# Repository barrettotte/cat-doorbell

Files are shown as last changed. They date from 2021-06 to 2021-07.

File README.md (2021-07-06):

# cat-doorbell

A proximity sensor to detect my cat outside my door and flash an LED at my desk.

## Summary

I generally have noise cancelling headphones on and my cat will sit outside my door
meowing late at night when it wants to come in.

This project has two modules, a transmitter and receiver.
The transmitter module will detect my cat using a proximity sensor and send an RF
signal to the receiver module. The receiver module will activate an LED for three seconds
upon receiving an RF signal.

On the receiver module there is an optional piezo speaker that can be muted/unmuted to 
trigger at the same time as the LED. I feel like it might get annoying hence the mute button.

## Part List

- 2 x Arduino Nano ATmega328
- 2 x NRF24L01 2.4GHz Transceiver module
- 2 x 100μF electrolytic capacitor
- 2 x Micro USB breakout board
- 2 x LD1117V33 3.3V linear voltage regulator
- 2 x Red LED
- 2 x 570Ω resistor
- 1 x 100Ω resistor
- 1 x Piezo Speaker
- 1 x Switch
- 1 x Ultrasonic module HC-SR04

## Images

### Receiver

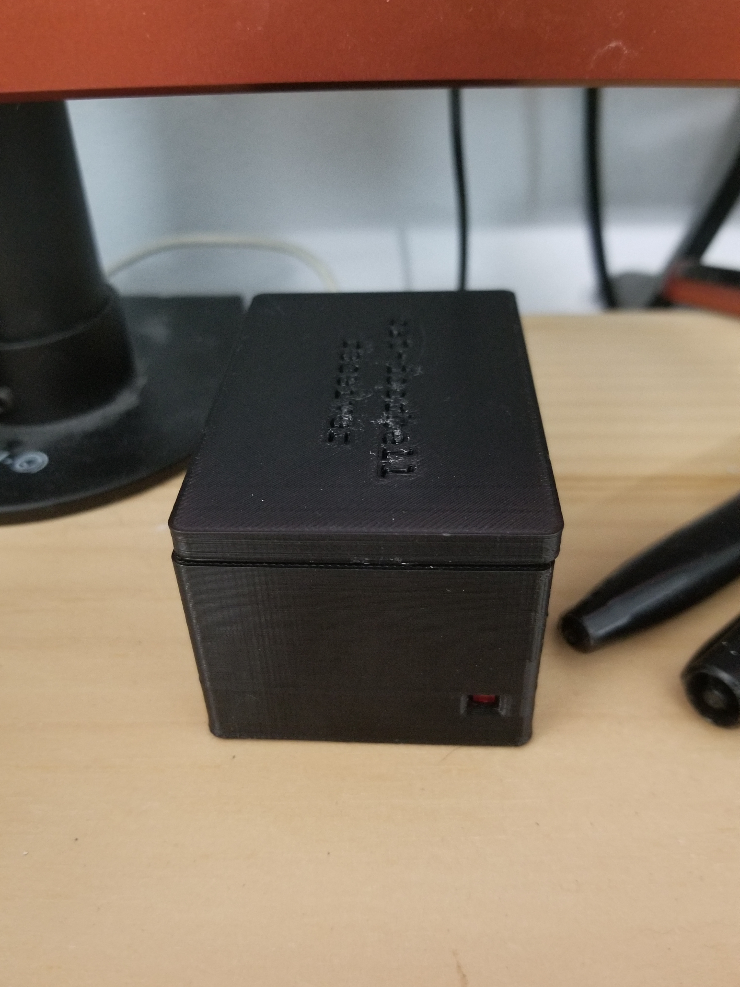
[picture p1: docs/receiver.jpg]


### Transmitter

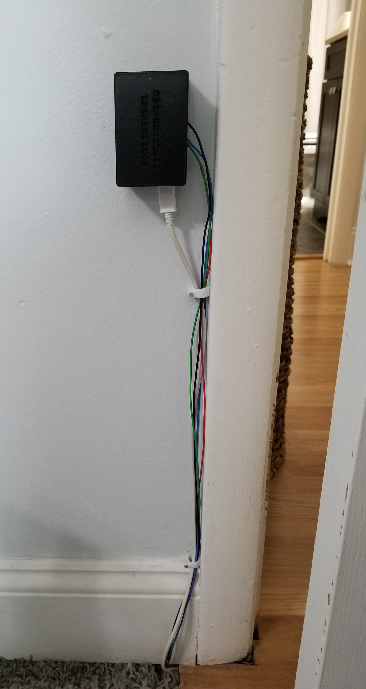
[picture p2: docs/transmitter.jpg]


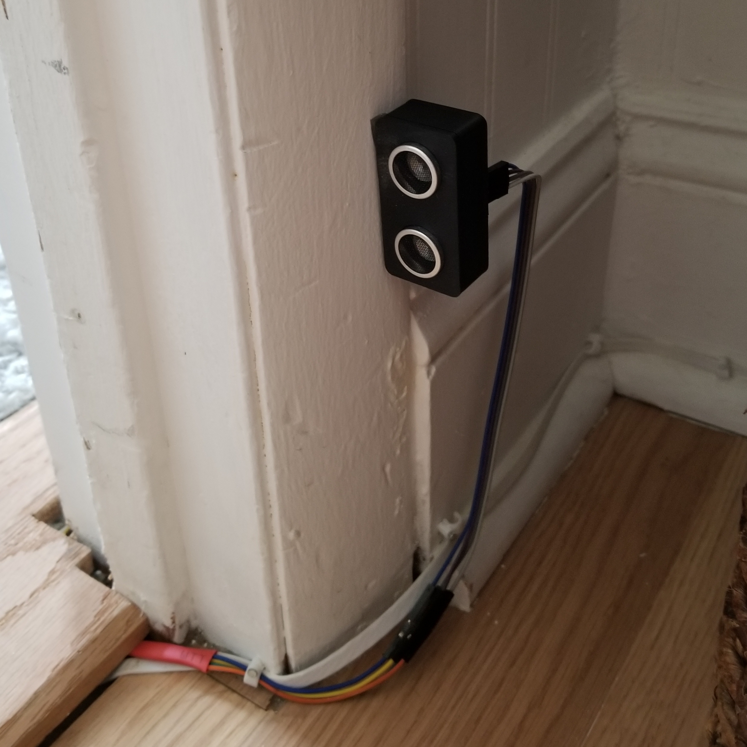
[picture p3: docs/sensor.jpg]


## Improvements

Stuff I thought about as the project was pretty much done

- Use terminal blocks instead of four dupont cables
- A potentiometer to adjust ultrasonic sensor max range (useful for tuning)

## References

- [Platformio SparkFun Arduino Nano ATmega328](https://docs.platformio.org/en/latest/boards/atmelavr/nanoatmega328.html)
- [HC-SR04 Ultrasonic Sensor - Last Minute Engineers](https://lastminuteengineers.com/arduino-sr04-ultrasonic-sensor-tutorial/)
- [NRF24L01 - Last Minute Engineers](https://lastminuteengineers.com/nrf24l01-arduino-wireless-communication/)

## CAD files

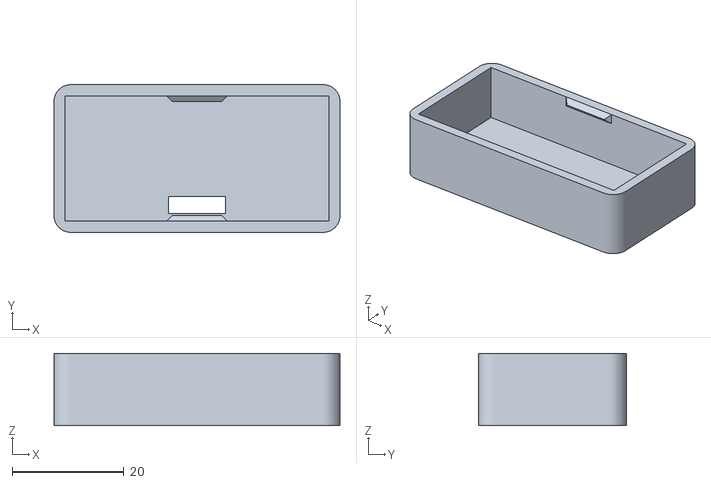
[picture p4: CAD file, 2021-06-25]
cad/HCSR04/HCSR04-bottom.stl
51.3 x 26.5 x 13.0

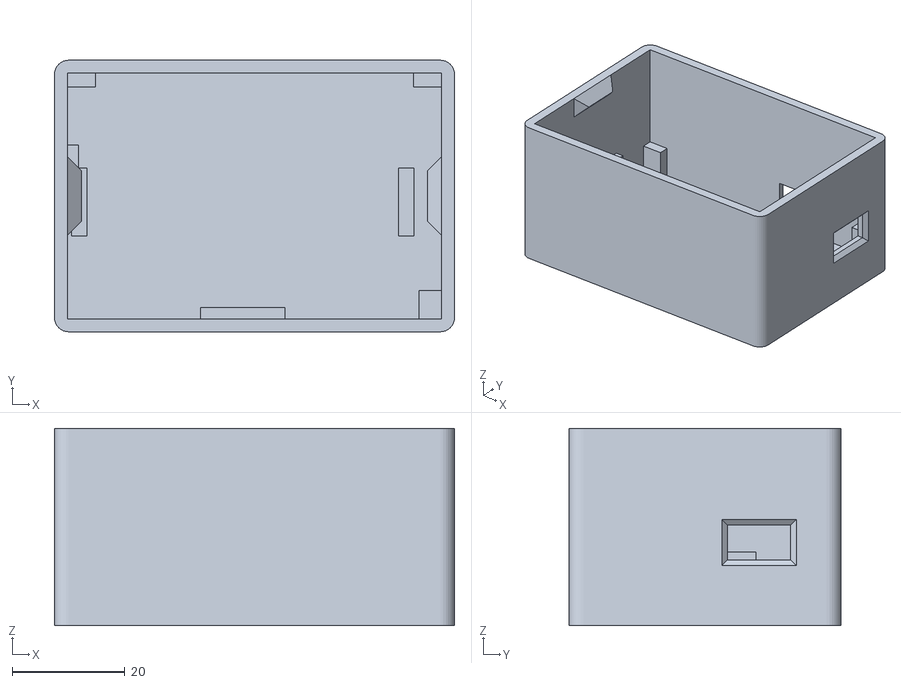
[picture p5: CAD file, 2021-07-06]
cad/receiver/receiver-bottom.stl
71.0 x 48.2 x 35.0

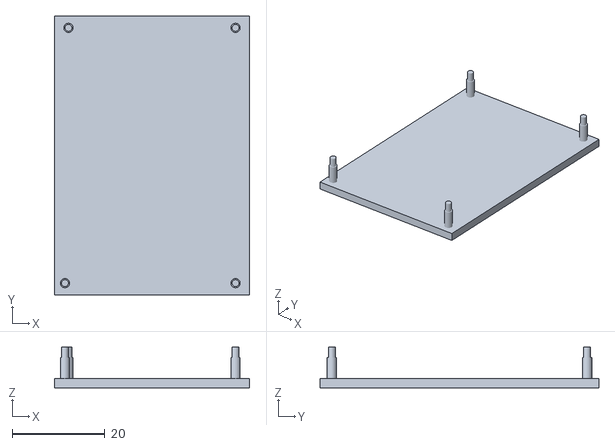
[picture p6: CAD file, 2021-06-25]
cad/test-pcb-riser.stl
42.0 x 60.0 x 8.80

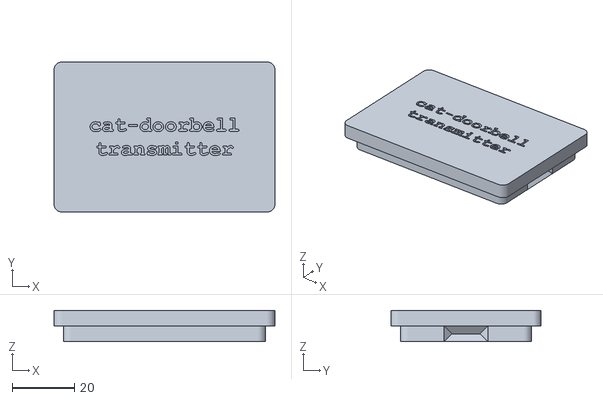
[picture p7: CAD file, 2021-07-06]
cad/transmitter/transmitter-top.stl
71.0 x 48.2 x 10.0

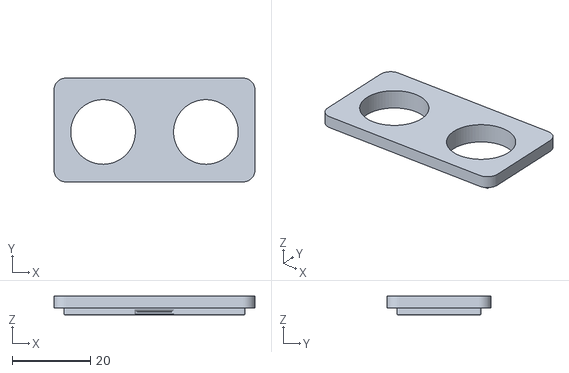
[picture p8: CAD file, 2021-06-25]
cad/HCSR04/HCSR04-top.stl
51.3 x 26.5 x 4.75

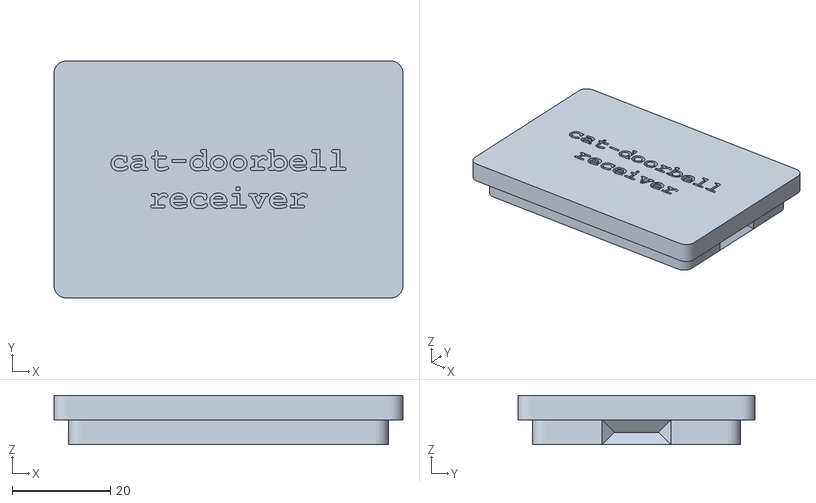
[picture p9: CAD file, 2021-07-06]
cad/receiver/receiver-top.stl
71.0 x 48.2 x 10.0

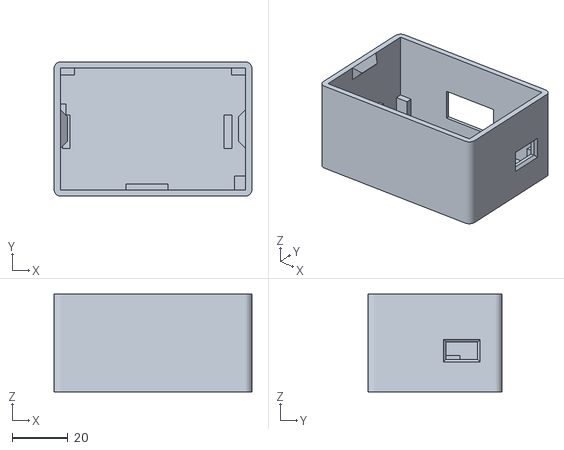
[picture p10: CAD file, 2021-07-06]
cad/transmitter/transmitter-bottom.stl
71.0 x 48.2 x 35.0

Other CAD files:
cad/HCSR04/HCSR04-cover.f3d
cad/receiver/receiver.f3d
cad/transmitter/receiver.f3d
cad/transmitter/transmitter.f3d

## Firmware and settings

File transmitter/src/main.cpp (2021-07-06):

// cat doorbell transmitter module

#include <Arduino.h>  // Arduino core
#include <RF24.h>     // RF 2.4GHz library
#include <nRF24L01.h> // 2.4GHz transceiver driver
#include <SPI.h>      // Serial Peripheral Interface

#define DEBUG   0     // toggle debug mode
#define MAX_CM 60     // range to trigger in CM; ~32" == 81cm

// pinout
#define ECHO_PIN   2  // D2  ; HC-SR04 echo
#define TRIG_PIN   3  // D3  ; HC-SR04 trigger
#define LED_PIN    5  // D5  ; LED activated when object in range of HC-SR04
#define CE_PIN     7  // D7  ; Chip Enable (CE) - set NRF24L01 to transmit/receive
#define CSN_PIN    8  // D8  ; Chip Select Not (CSN) - NRF24L01 listen to SPI port for data
#define MOSI_PIN  11  // D11 ; Master Out Slave In (MOSI) - SPI input to NRF24L01
#define MISO_PIN  12  // D12 ; Master In Slave Out (MISO) - SPI output to NRF24L01
#define SCK_PIN   13  // D13 ; Serial Clock (SCK) - clock pulse from SPI bus master

// debug precompile
#if DEBUG == 1
  #define DEBUG_PRINT(s)   Serial.print(s)
  #define DEBUG_PRINTLN(s) Serial.println(s)
#else
  #define DEBUG_PRINT(s)
  #define DEBUG_PRINTLN(s)
#endif

// constants
const uint64_t PIPE_ADDR = 0x63617431; // "cat1" in hex

// prototypes
void initRadio();

// globals
RF24 radio(CE_PIN, CSN_PIN);
float distance, duration;
uint8_t payload[1];


void setup(){
    pinMode(TRIG_PIN, OUTPUT);  
    pinMode(ECHO_PIN, INPUT);
    pinMode(LED_PIN, OUTPUT);

    #if DEBUG == 1
      Serial.begin(9600);
      while (!Serial);
    #endif
    DEBUG_PRINTLN("\nSerial monitor initialized.");

    initRadio();
    payload[0] = '!';
    delay(1000);
}

// send ultrasonic ping to get distance of object
void ping(){
    digitalWrite(TRIG_PIN, LOW);
    delayMicroseconds(2);
    digitalWrite(TRIG_PIN, HIGH);
    delayMicroseconds(10);

    duration = pulseIn(ECHO_PIN, HIGH);
    distance = duration * (0.034 / 2); // 1/2 speed of sound wave

    DEBUG_PRINT("Distance: ");
    DEBUG_PRINT(distance);
    DEBUG_PRINTLN(" cm");
}

void loop(){
    ping(); // ping for object

    // check if cat is in front of door
    if(distance < MAX_CM){
        digitalWrite(LED_PIN, HIGH);
        delay(500);

        if(radio.write(&payload, sizeof(payload))) {
            DEBUG_PRINT("Sent payload: ");
            DEBUG_PRINTLN(payload[0]);

            // visualize payload sent
            for(int i = 0; i < 8; i++) {
                digitalWrite(LED_PIN, LOW);
                delay(50);
                digitalWrite(LED_PIN, HIGH);
                delay(50);
            }
        } else {
            DEBUG_PRINTLN("Tx failed");
        }
    } else{
        digitalWrite(LED_PIN, LOW);
    }
    delay(500);
}

// initialize radio module
void initRadio(){
    radio.begin();
    radio.setChannel(108); // channel above most WiFi
    radio.setDataRate(RF24_250KBPS);
    radio.setRetries(15, 15);  // delay * 250 us,count
    radio.setPayloadSize(sizeof(payload));
    radio.setPALevel(RF24_PA_MIN);
    radio.openWritingPipe(PIPE_ADDR);
    radio.stopListening(); // set as transmitter
}

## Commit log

2021-05-29 switching to 2.4GHz modules
2021-05-31 setup with Arduino Nano
2021-06-05 fix receiver LED
2021-06-06 cad for receiver enclosure
    [receiver-enclosure.stl, receiver-lid.stl, receiver.f3d]
2021-06-07 HCSR04 cover
    [HCSR04-enclosure.stl, HCSR04-lid.stl, HCSR04.f3d]
2021-06-07 add PCB riser test
    [receiver.f3d, test-pcb-riser.stl]
2021-06-07 add receiver schematic
2021-06-25 HCSR04 cover cad
    [HCSR04-bottom.stl, HCSR04-cover.f3d, HCSR04-enclosure.stl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]
2021-07-06 exported Fusion360 project files
    [receiver.f3d, transmitter.f3d]
